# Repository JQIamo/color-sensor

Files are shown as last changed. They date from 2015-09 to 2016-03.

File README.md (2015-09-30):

# color-sensor


## Project Location
Find us on GitHub: http://git.io/vc8Iy or directly https://github.com/JQIamo/color-sensor/

 [color-sensor](https://github.com/JQIamo/color-sensor/) is licensed under a [Creative Commons Attribution-ShareAlike 4.0 International License](http://creativecommons.org/licenses/by-sa/4.0/).

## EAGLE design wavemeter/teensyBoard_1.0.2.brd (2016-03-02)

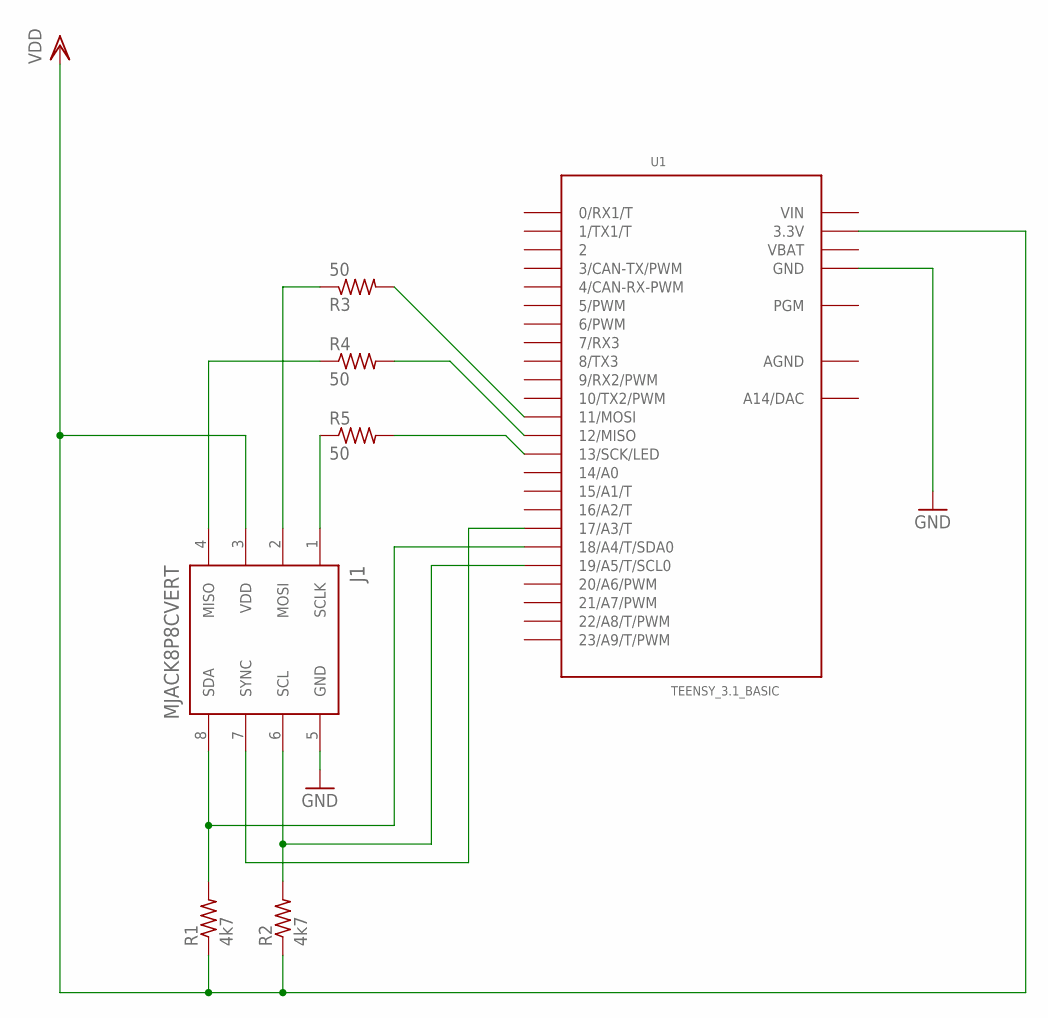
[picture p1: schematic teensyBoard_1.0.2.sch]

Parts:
J1: MJACK8P8CVERT; MJACK8P8C
R1, R2: 4k7; R0603
R3, R4, R5: 50; R0603
U1: TEENSY_3.1_BASIC

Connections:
AGND: U1.AGND
GND: J1.5 (GND), U1.GND, U1.GND1 (GND)
unnamed: R3.2, U1.11 (11/MOSI)
unnamed: J1.6 (SCL), R2.2, U1.19/A5 (19/A5/T/SCL0)
unnamed: J1.4 (MISO), R4.1
unnamed: R4.2, U1.12 (12/MISO)
unnamed: J1.1 (SCLK), R5.1
unnamed: R5.2, U1.13 (13/SCK/LED)
unnamed: J1.8 (SDA), R1.2, U1.18/A4 (18/A4/T/SDA0)
unnamed: J1.7 (SYNC), U1.17/A3 (17/A3/T)
unnamed: J1.2 (MOSI), R3.1
VBAT: U1.VBAT
VDD: J1.3 (VDD), R1.1, R2.1, U1.3.3V, U1.3.3V1 (3.3V)
VIN: U1.VIN

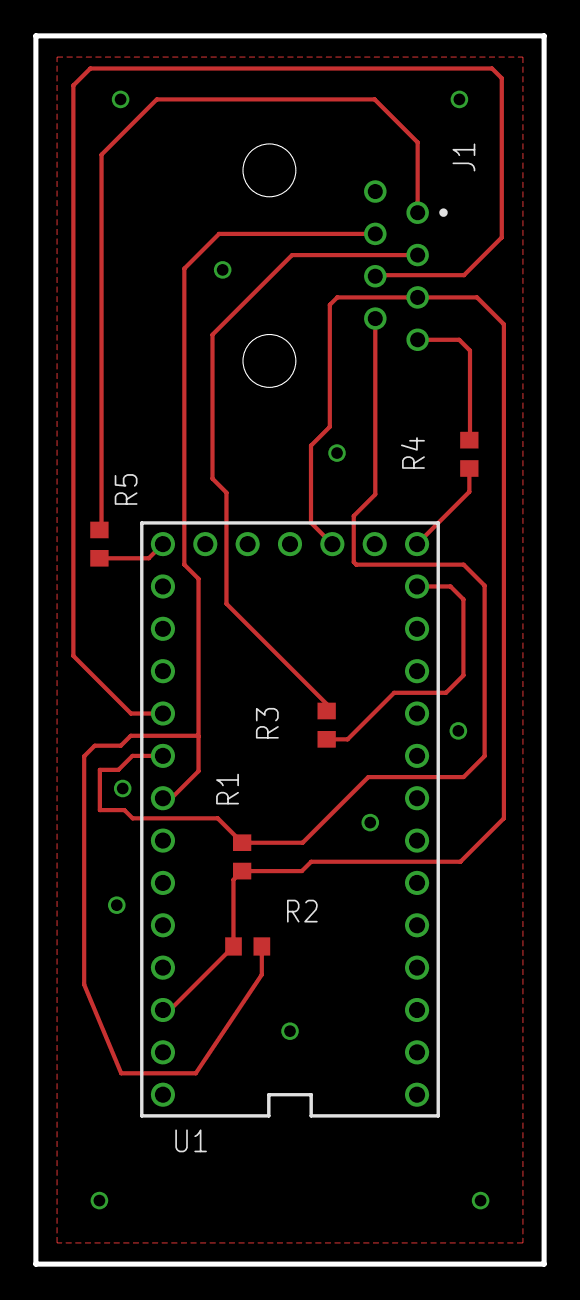
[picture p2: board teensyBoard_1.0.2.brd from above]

Board: 2 copper layers, 30.5 x 73.7 mm, 7 parts (0 on the bottom side), 11 nets.

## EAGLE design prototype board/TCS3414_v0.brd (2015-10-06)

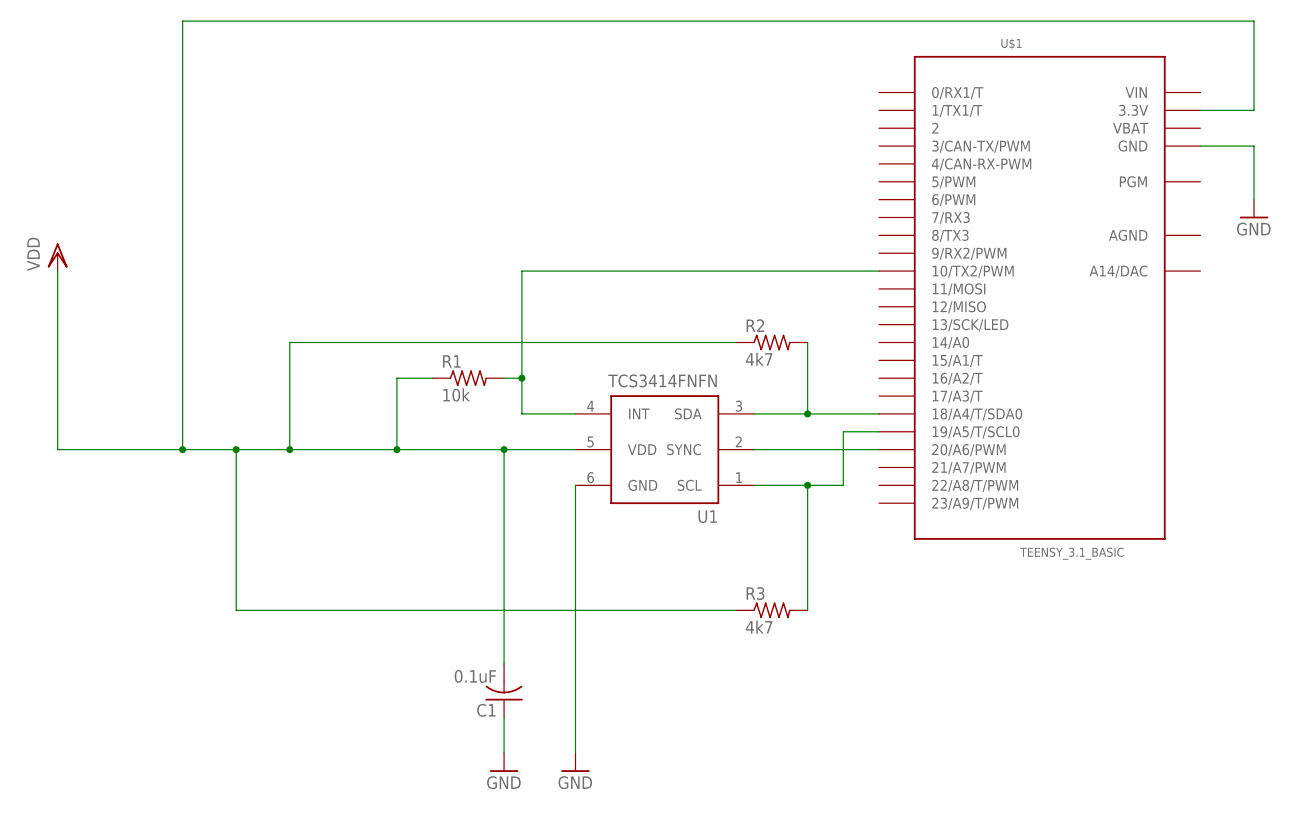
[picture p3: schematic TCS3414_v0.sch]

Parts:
C1: 0.1uF; C0603
R1: 10k; R0603
R2, R3: 4k7; R0603
U1: TCS3414FNFN; TCS3414FN
U$1: TEENSY_3.1_BASIC

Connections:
AGND: U$1.AGND
GND: C1.1, U1.6 (GND), U$1.GND, U$1.GND1 (GND)
unnamed: R1.2, U1.4 (INT), U$1.10 (10/TX2/PWM)
unnamed: R2.2, U1.3 (SDA), U$1.18/A4 (18/A4/T/SDA0)
unnamed: R3.2, U1.1 (SCL), U$1.19/A5 (19/A5/T/SCL0)
unnamed: U1.2 (SYNC), U$1.20/A6 (20/A6/PWM)
VBAT: U$1.VBAT
VDD: C1.2, R1.1, R2.1, R3.1, U1.5 (VDD), U$1.3.3V, U$1.3.3V1 (3.3V)
VIN: U$1.VIN

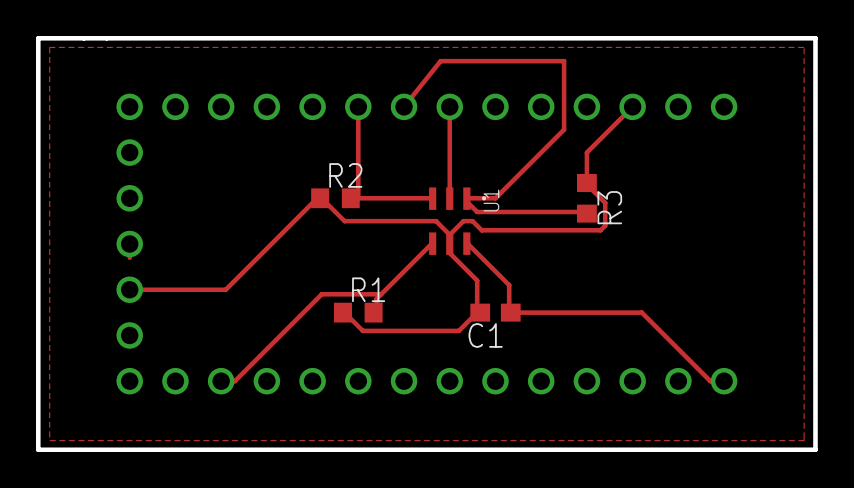
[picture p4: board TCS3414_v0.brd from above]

Board: 2 copper layers, 43.2 x 22.9 mm, 6 parts (1 on the bottom side), 6 nets.

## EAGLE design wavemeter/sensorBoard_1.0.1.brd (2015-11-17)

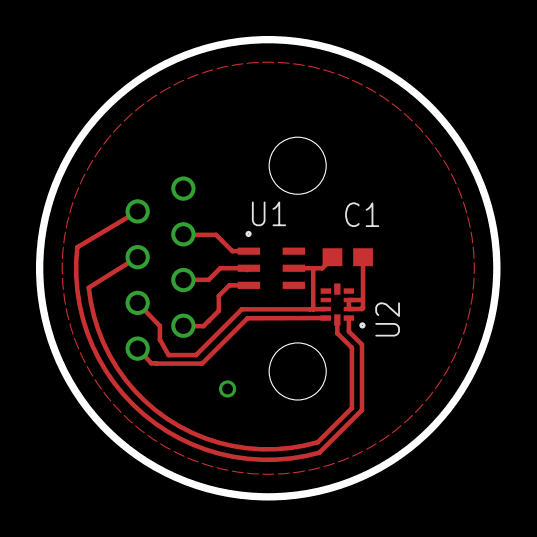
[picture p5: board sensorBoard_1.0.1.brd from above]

Board: 2 copper layers, 25.4 x 25.4 mm, 4 parts (1 on the bottom side), 8 nets.

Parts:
C1: 0.2uF; C0603
J1: MJACK8P8CVERT; MJACK8P8C
U1: TCS3414FN; TCS3414
U2: ADS1118RUG; ADS1118

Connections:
GND: C1.2, J1.5, U1.6, U2.2, U2.3
unnamed: J1.6, U1.1
unnamed: J1.7, U1.2
unnamed: J1.8, U1.3
unnamed: C1.1, J1.3, U1.5, U2.8
unnamed: J1.4, U2.9
unnamed: J1.2, U2.10
unnamed: J1.1, U2.1

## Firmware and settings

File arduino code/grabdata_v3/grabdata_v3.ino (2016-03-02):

// -------------------------------------------------------------------------------------------
// Teensy3.0/3.1/LC I2C Interrupt Test
// 15May13 Brian (nox771 at gmail.com)
// -------------------------------------------------------------------------------------------
//
// This creates an I2C master device which will issue I2C commands from inside a periodic
// interrupt (eg. reading a sensor at regular time intervals).  For this test the Slave device
// will be assumed to be that given in the i2c_t3/slave sketch.
//
// The test will start when the Serial monitor opens.
//
// This example code is in the public domain.
//
// -------------------------------------------------------------------------------------------
// Slave protocol is as follows:
// -------------------------------------------------------------------------------------------
// WRITE - The I2C Master can write to the device by transmitting the WRITE command,
//         a memory address to store to, and a sequence of data to store.
//         The command sequence is:
//
// START|I2CADDR+W|WRITE|MEMADDR|DATA0|DATA1|DATA2|...|STOP
//
// where START     = I2C START sequence
//       I2CADDR+W = I2C Slave address + I2C write flag
//       WRITE     = WRITE command
//       MEMADDR   = memory address to store data to
//       DATAx     = data byte to store, multiple bytes are stored to increasing address
//       STOP      = I2C STOP sequence
// -------------------------------------------------------------------------------------------
// READ - The I2C Master can read data from the device by transmitting the READ command,
//        a memory address to read from, and then issuing a STOP/START or Repeated-START,
//        followed by reading the data.  The command sequence is:
//
// START|I2CADDR+W|READ|MEMADDR|REPSTART|I2CADDR+R|DATA0|DATA1|DATA2|...|STOP
//
// where START     = I2C START sequence
//       I2CADDR+W = I2C Slave address + I2C write flag
//       READ      = READ command
//       MEMADDR   = memory address to read data from
//       REPSTART  = I2C Repeated-START sequence (or STOP/START if single Master)
//       I2CADDR+R = I2C Slave address + I2C read flag
//       DATAx     = data byte read by Master, multiple bytes are read from increasing address
//       STOP      = I2C STOP sequence
// -------------------------------------------------------------------------------------------
// SETRATE - The I2C Master can adjust the Slave configured I2C rate with this command
//           The command sequence is:
//
// START|I2CADDR+W|SETRATE|RATE|STOP
//
// where START     = I2C START sequence
//       I2CADDR+W = I2C Slave address + I2C write flag
//       SETRATE   = SETRATE command
//       RATE      = I2C RATE to use (must be from i2c_rate enum list, eg. I2C_RATE_xxxx)
// -------------------------------------------------------------------------------------------

#include <i2c_t3.h>
#include <TimerOne.h>

// command definitions
#define WRITE    0x10
#define READ     0x20
#define SETRATE  0x30

// TCS-3414 register addresses 
#define TCS       0x39
#define CONTROL   0x80
#define TIMING    0x81

// Sync integration constants
#define INT_TIME  500000
#define SYNC_PIN 17

// Function prototypes
void readSlave(void);
void syncInt(void);

IntervalTimer slaveTimer;
size_t addr=0, len;
volatile boolean intVar = 1;

void setup()
{
  pinMode(LED_BUILTIN,OUTPUT);            // LED blink output
  pinMode(SYNC_PIN, OUTPUT);              // set sync pin to output
  digitalWrite(SYNC_PIN, LOW);            // set teensy SYNC pin low 
                                          // (rising edge tells TCS sensor to start integration)
    
  // setup for Master mode, pins 18/19, external pullups, 400kHz
  Wire.begin(I2C_MASTER, 0x00, I2C_PINS_18_19, I2C_PULLUP_EXT, I2C_RATE_400);
  // setup for Slave mode (sensor), TCS address, pins 18/19, external pullups, 400kHz
  Wire.begin(I2C_SLAVE, TCS, I2C_PINS_18_19, I2C_PULLUP_EXT, I2C_RATE_400);
    
  Serial.begin(9600);
  delay(10);                              

  Wire.beginTransmission(TCS);           
  Wire.write(CONTROL);                    // access control register
  Wire.write(0x03);                       // powers up TCS chip / enable ADC
  Wire.endTransmission();            

  Wire.beginTransmission(TCS);            
  Wire.write(TIMING);                     // access timing register
  Wire.write(0x70);                       // sync integration over rising edge
  Wire.endTransmission();              
  delay(10);

  //while(!Serial);                         // wait to start
  
  digitalWrite(SYNC_PIN, HIGH);           // start ADC integration cycle
  slaveTimer.begin(syncInt, INT_TIME);    // start integration timer
  delayMicroseconds(150);                 // minimum pulse width 50us
  digitalWrite(SYNC_PIN, LOW);            // end pulse
}

// sync interrupt function - ends the integration cycle by pulling the 
// sync pin high and setting intVar to 0 so that loop commences
void syncInt(void) 
{
  digitalWrite(SYNC_PIN, HIGH);                 // end ADC integration cycle
  intVar = 0;
}

void loop()
{
    while(intVar == 1);                 // wait until ADC integration cycle finishes

    slaveTimer.end();
    delayMicroseconds(150);               // minimum pulse width 50 us
    digitalWrite(SYNC_PIN, LOW);              // finish ending pulse
         
    noInterrupts();
    readSlave();
    intVar = 1;
    interrupts();

    digitalWrite(SYNC_PIN, HIGH);                 // start ADC integration cycle
    slaveTimer.begin(syncInt, INT_TIME);    // start integration timer
    delayMicroseconds(100);                 // minimum pulse width 50us
    digitalWrite(SYNC_PIN, LOW);                  // end pulse
}
    


void readSlave(void)
{
    // storage of channel data; g_low = green channel low byte
    uint8_t g_low, g_high, r_low, r_high,
            b_low, b_high, c_low, c_high;
   
    // variables for total channel values (2 bytes per channel)
    int green, red, blue, clr;
        
    digitalWrite(LED_BUILTIN,HIGH);     // pulse LED when reading

     
    // diable ADC integration
    Wire.beginTransmission(TCS);        // talk to slave
    Wire.write(CONTROL);                // access control register
    Wire.write(0x01);                   // disable ADC integration (toggle)
    Wire.endTransmission();             // blocking Tx
      
    // read values
    Wire.beginTransmission(TCS);        // talk to slave
    Wire.write(0xB6);                   // command for clear lower data byte
    Wire.endTransmission(I2C_NOSTOP);   // blocking Tx, no STOP
    Wire.requestFrom(TCS,2,I2C_STOP);   // request 2 bytes
    c_low = Wire.readByte();
    c_high = Wire.readByte();
    clr = c_low+c_high*256;
    
    Wire.beginTransmission(TCS);        // talk to slave
    Wire.write(0xB0);                   // access lower green data byte
    Wire.endTransmission(I2C_NOSTOP);   // blocking Tx, no STOP
    Wire.requestFrom(TCS,2,I2C_STOP);   // request 2 bytes
    g_low = Wire.readByte();
    g_high = Wire.readByte();
    green = g_low+g_high*256;

    Wire.beginTransmission(TCS);        // talk to slave
    Wire.write(0xB2);                   // access lower red data byte
    Wire.endTransmission(I2C_NOSTOP);   // blocking Tx, no STOP
    Wire.requestFrom(TCS,2,I2C_STOP);   // request 2 bytes
    r_low = Wire.readByte();
    r_high = Wire.readByte();
    red = r_low+r_high*256;

    Wire.beginTransmission(TCS);        // talk to slave
    Wire.write(0xB4);                   // access lower blue data byte
    Wire.endTransmission(I2C_NOSTOP);   // blocking Tx, no STOP
    Wire.requestFrom(TCS,2,I2C_STOP);    // request 2 bytes
    b_low = Wire.readByte();
    b_high = Wire.readByte();
    blue = b_low+b_high*256;
   
    // Print data from channels    
    Serial.printf("clr: %d, g: %d, b: %d, r: %d\n", clr, green, blue, red);

    digitalWrite(LED_BUILTIN,LOW);
    
    // enable ADC integration
    Wire.beginTransmission(TCS);        
    Wire.write(CONTROL);                // access control register
    Wire.write(0x03);                   // enable ADC integration
    Wire.endTransmission();                              
}

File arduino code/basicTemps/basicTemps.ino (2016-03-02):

#include <SPI.h>
#include <stdio.h>
#include <string.h>
#include <stdlib.h>

SPISettings settingsA(65000, MSBFIRST, SPI_MODE1);

void setup()
{
    
    //Start serial comms
    Serial.begin(9600);
    delay(10);                           

    //Start & configure SPI settings
    SPI.begin();
    delay(5);
    SPI.setClockDivider(SPI_CLOCK_DIV16);
    delay(5);
    SPI.setBitOrder(MSBFIRST);
    delay(5);
    SPI.setDataMode(SPI_MODE1);
    delay(5);
}

void loop()
{
    int configMSB, configLSB, dataMSB, dataLSB;
    float temp;
    
    dataMSB = SPI.transfer(B10000101);
    dataLSB = SPI.transfer(B10011011);
    configMSB = SPI.transfer(B10000101);    
    configLSB = SPI.transfer(B10011011);
 
    Serial.printf("%d, %d, %d, %d\n", configMSB, configLSB, dataMSB,dataLSB);

    Serial.printf("dataMSB = %s\n", byte_to_binary(dataMSB));
    Serial.printf("dataLSB = %s\n", byte_to_binary(dataLSB));

    temp = (dataMSB*64+dataLSB) * 0.03125;

    Serial.printf("%5.5f\n\n", temp);
    
    delay(2000);
}

const char *byte_to_binary(int x)
{
  static char b[9];
  b[0] = '\0';

  int z;
  for (z = 128; z > 0; z >>=1) {
    strcat(b, ((x & z) == z) ? "1" : "0");
  }
  
  return b;
}

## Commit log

2015-10-04 Add Aaron's Prototype Board
    Includes his generated TCS3414 library as well as the first schematic
    and layout for testing the color sensor.
    Also has mcu-accessories.lbr from the JQIamo/mcu-accessories repository.
    [TCS3414_v0.brd, TCS3414_v0.sch]
2015-10-06 Changed resistor values
    2.5k to 10k and 1.3k to 4.7k resistor changes
    [TCS3414_v0.brd, TCS3414_v0.sch]
2015-10-15 Color sensor circuit Arduino code
    Currently grabs 4 readings per second with a 100us integration cycle
2015-10-16 Updated version of sensor data gathering program
    Nothing major, mostly style changes
2015-10-20 Adding new Arduino code with sync functionality for sensor chip
    New file w sync functionality
2015-11-17 Production v1.0.0
    Eagle schematic, board, and library files (also added datasheets for new
    parts ADS1118 and Ethernet Jack)
    [TCS Sensor Graph Raw Data.xlsx, wavemeter_v1.brd, wavemeter_v1.sch]
2016-01-28 Clean up and organization of folders
    Also fixed crossed MOSI/MISO wires on the teensyBoard eagle files
    [TCS3414_v0.brd, TCS3414_v0.sch, sensorBoard_1.0.brd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]
2016-01-28 Updated Eagle files
    Fixed crossed wires on teensyBoard
    [sensorBoard_1.0.1.brd, teensyBoard_1.0.1.brd, teensyBoard_1.0.1.sch]
2016-02-01 Fixed time sync code
    [grabdata_sync.ino]
2016-03-02 New Eagle layout
    Moved all wiring to top of board
    [teensyBoard_1.0.2.brd, teensyBoard_1.0.2.sch]
2016-03-04 Sensor data runs

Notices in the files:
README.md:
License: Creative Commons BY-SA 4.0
